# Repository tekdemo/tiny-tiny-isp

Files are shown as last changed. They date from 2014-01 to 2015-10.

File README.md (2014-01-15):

tiny-tiny-isp
=============
A very small ISP programmer for AVR chips.

Based heavily off of the VUSBTiny-AVR-SPI-Programmer](http://www.instructables.com/id/VUSBTiny-AVR-SPI-Programmer/), with some additional features. 

Features
========

- Level shifting options for 3.3V, 5V programming

- Option for high-voltage reset

- Very small footprint

- Low cost design

- Ability to use pogo pins for quick programming, or use headers for prototyping

*Wishlist*

- Integrate USB-COM support to allow target to pass messages to host via SPI

Board Changelog
========

*V2*

- Fix current limiting resistors being on the wrong side of the diode

- Fix missing pull-up resistors on target side of level-shifting mosfets

- Add a place to connect 12V for high-voltage reset 

- Improved bottom graphic

- Improved pad layout for pogo pins

*V1*

- Initial Design board layout

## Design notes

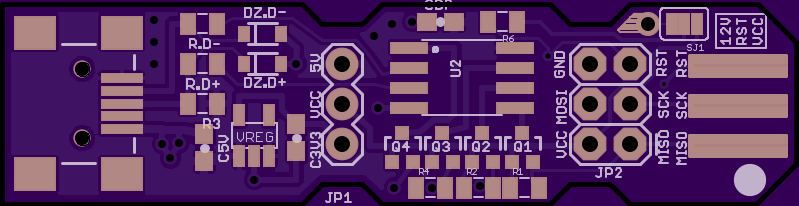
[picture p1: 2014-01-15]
top.png

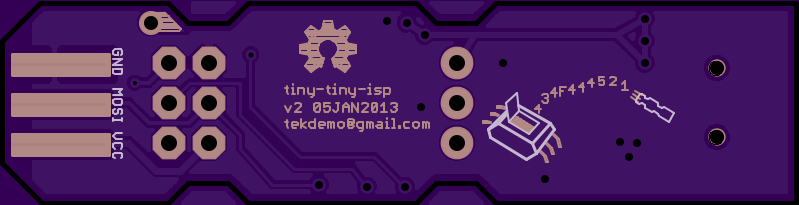
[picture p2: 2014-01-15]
bottom.png

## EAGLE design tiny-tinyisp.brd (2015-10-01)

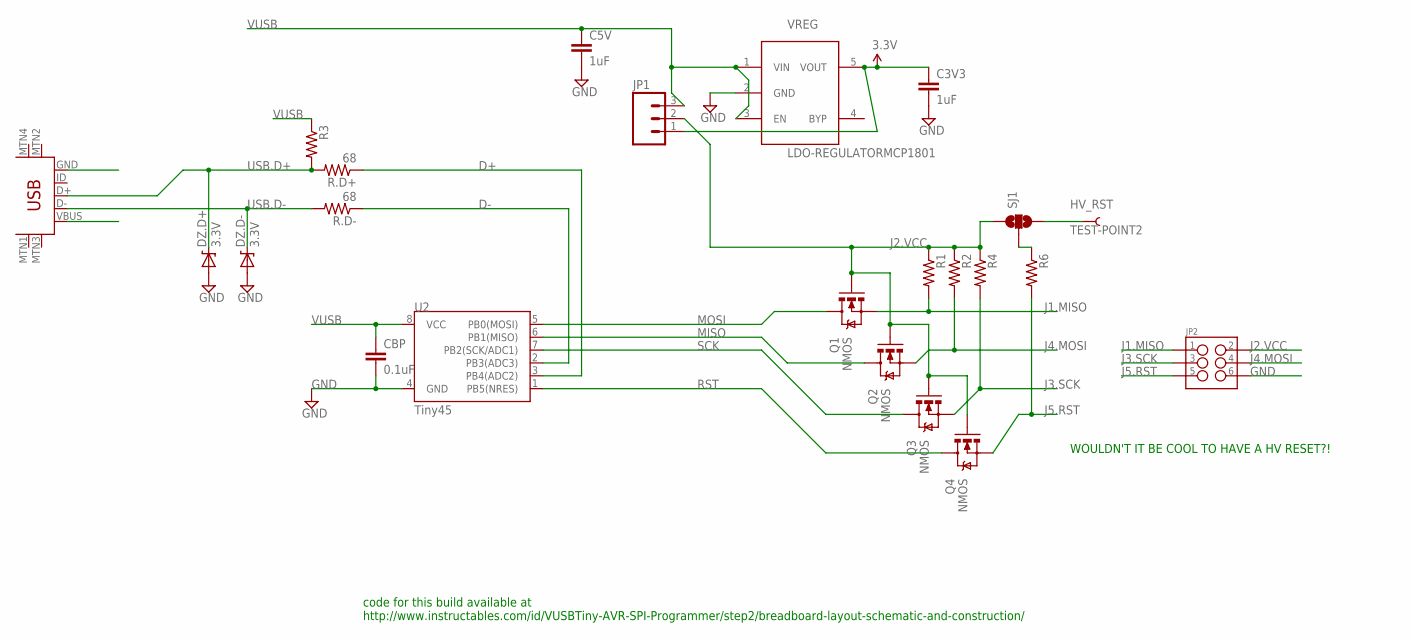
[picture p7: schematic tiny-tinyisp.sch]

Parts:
C3V3, C5V: 1uF; 0603-CAP
CBP: 0.1uF; 0603-CAP
DZ.D+, DZ.D-: 3.3V; SOD-323
HV_RST: TEST-POINT2; PAD.02X.02
JP1: M03PTH; 1X03
JP2: M03X22X3_SILK_SM; 2X3
Q1, Q2, Q3, Q4: NMOS; SOT323
R1, R2, R3, R4, R6: RESISTOR0805-RES; 0805
R.D+, R.D-: 68; 0805
SJ1: SOLDERJUMPER_2WAYPASTE1&2; SJ_3_PASTE1&2
U2: Tiny45; SO08-EIAJ
U$1: USB-MINIB
VREG: LDO-REGULATORMCP1801; SOT23-5L

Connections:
3.3V: C3V3.1, JP1.1, VREG.5 (VOUT)
D+: R.D+.1, U2.3 (PB4(ADC2))
D-: R.D-.1, U2.2 (PB3(ADC3))
GND: C3V3.2, C5V.2, CBP.2, DZ.D+.2 (A), DZ.D-.2 (A), JP2.6, U2.4 (GND), U$1.GND, VREG.2 (GND)
HVRST: HV_RST.P$1, SJ1.3
J1.MISO: JP2.1, Q1.2 (S), R1.2
J2.VCC: JP1.2, JP2.2, Q1.1 (G), Q2.1 (G), Q3.1 (G), Q4.1 (G), R1.1, R2.1, R4.1, SJ1.1
J3.SCK: JP2.3, Q3.2 (S), R4.2
J4.MOSI: JP2.4, Q2.2 (S), R2.2
J5.RST: JP2.5, Q4.2 (S), R6.2
MISO: Q2.3 (D), U2.6 (PB1(MISO))
MOSI: Q1.3 (D), U2.5 (PB0(MOSI))
unnamed: R6.1, SJ1.2
RST: Q4.3 (D), U2.1 (PB5(NRES))
SCK: Q3.3 (D), U2.7 (PB2(SCK/ADC1))
USB.D+: DZ.D+.1 (C), R3.2, R.D+.2, U$1.D+
USB.D-: DZ.D-.1 (C), R.D-.2, U$1.D-
VUSB: C5V.1, CBP.1, JP1.3, R3.1, U2.8 (VCC), U$1.VBUS, VREG.1 (VIN), VREG.3 (EN)

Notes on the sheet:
code for this build available at http://www.instructables.com/id/VUSBTiny-AVR-SPI-Programmer/step2/breadboard-layout-schematic-and-construction/
WOULDN'T IT BE COOL TO HAVE A HV RESET?!

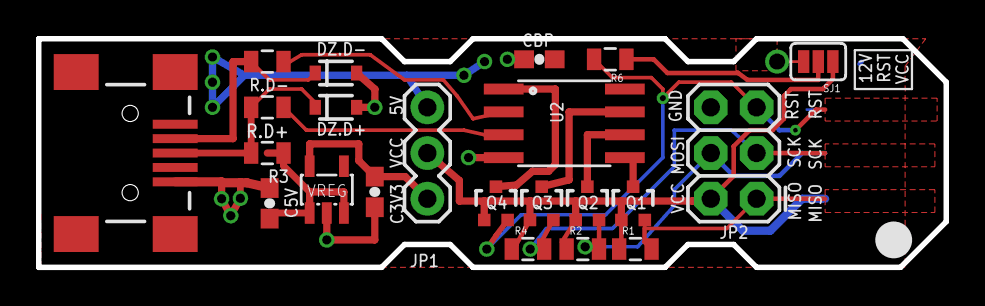
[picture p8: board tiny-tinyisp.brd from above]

Board: 2 copper layers, 50.4 x 12.7 mm, 23 parts (0 on the bottom side), 18 nets.

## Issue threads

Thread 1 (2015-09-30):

Eagle and Gerbers still at V1

DirtyEngineer, 2015-09-30:
Just a heads up. The eagle files and gerbers are still of your V1 board.  Do you have the files for the V2 board?  Also, what firmware are you using for the HVSP rest option?

tekdemo, 2015-10-01:
You're correct! I do have a second board rev, which I'll push here. I don't, however, have any firmware written for it. I got away from the project (and the need for it) before I got anything put together.

tekdemo, 2015-10-01:
Actually, I'd be careful with the RESET line, since I'm not certain it'll work as anticipated. I have the mosfets reversed, which makes the 12V line go straight over to the programmer uC, and is likely to fry several things.

In theory, it wouldn't need direct firmware control, as the HVRST line would simply float to 12V when the reset enable line is active. However, it's been quite a while since I've verified the firmware update procedures on AVR chips.

DirtyEngineer, 2015-10-02:
Thanks for looking in this and for the info about the HVSP.
Cheers

Closed 2015-10-02.

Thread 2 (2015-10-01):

Level Shifting Mosfets backwards for protecting IC with HV RST

tekdemo, 2015-10-01:
It works for stepping down 5v to a 3v drive, but doesn't work for 3.3/5V or 5V with a 12V reset line.

Suggested fix is replacing the mosfets with a level shifting totem driver, such as op amps that can properly buffer the IC.

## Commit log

2014-01-15 Initial Commit, starting at V2
    [tiny-tinyisp.brd, tiny-tinyisp.sch]
2014-03-05 Whitespace change to force gen previews
    [tiny-tinyisp.brd]
2014-03-05 Version 2 of the board
    Fixed level-shifting diode on the wrong side
    added in an option for HV reset
    [tiny-tinyisp.brd, tiny-tinyisp.sch]
2015-10-01 Properly update files to V2
    [tiny-tinyisp.brd, tiny-tinyisp.sch]

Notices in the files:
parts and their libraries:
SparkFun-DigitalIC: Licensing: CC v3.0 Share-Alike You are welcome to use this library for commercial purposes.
